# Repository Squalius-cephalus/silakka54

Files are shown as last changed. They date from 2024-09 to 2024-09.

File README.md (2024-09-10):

# Silakka54

Silakka54 is a RP2040 Zero based 54-key column staggered split keyboard. PCB uses hotswap sockets. Design is inpired from REVIUNG41 and Corne keyboards.

PCB is designed for MX style key switches. Current top plate only supports MX style switches. 5-pin switches is supported. I recommend using Vial firmware.

[QMK](https://github.com/qmk/qmk_firmwarehttp:// "QMK") and [Vial](https://github.com/vial-kb/vial-qmk "Vial") firmwares has very barebones key mapping. Good for quick testing.

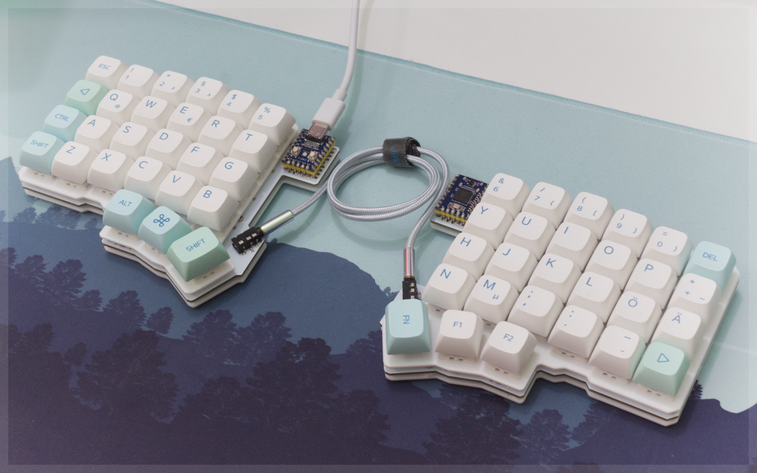
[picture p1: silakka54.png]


You can find build guide [here.](https://github.com/Squalius-cephalus/silakka54/blob/main/buildguide/README.md "here.")

PCB design uses footprints from [ScottoKeebs](https://github.com/joe-scotto/scottokeebs/tree/main/Extras/ScottoKicad "ScottoKeebs") and [kbd library.](https://github.com/foostan/kbd "kbd library.")

### TODO
1. Clean up code
2. Add RGB support
3. Make default QMK keymap usable

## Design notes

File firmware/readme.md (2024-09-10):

# silakka54

silakka54

*A short description of the keyboard/project*

* Keyboard Maintainer: [Squalius-cephalus](https://github.com/Squalius-cephalus)
* Hardware Supported: *The PCBs, controllers supported*
* Hardware Availability: *Links to where you can find this hardware*

Make example for this keyboard (after setting up your build environment):

    make silakka54:default

Flashing example for this keyboard:

    make silakka54:default:flash

See the [build environment setup](https://docs.qmk.fm/#/getting_started_build_tools) and the [make instructions](https://docs.qmk.fm/#/getting_started_make_guide) for more information. Brand new to QMK? Start with our [Complete Newbs Guide](https://docs.qmk.fm/#/newbs).

## Bootloader

Enter the bootloader in 3 ways:

* **Bootmagic reset**: Hold down the key at (0,0) in the matrix (usually the top left key or Escape) and plug in the keyboard
* **Physical reset button**: Briefly press the button on the back of the PCB - some may have pads you must short instead
* **Keycode in layout**: Press the key mapped to `QK_BOOT` if it is available

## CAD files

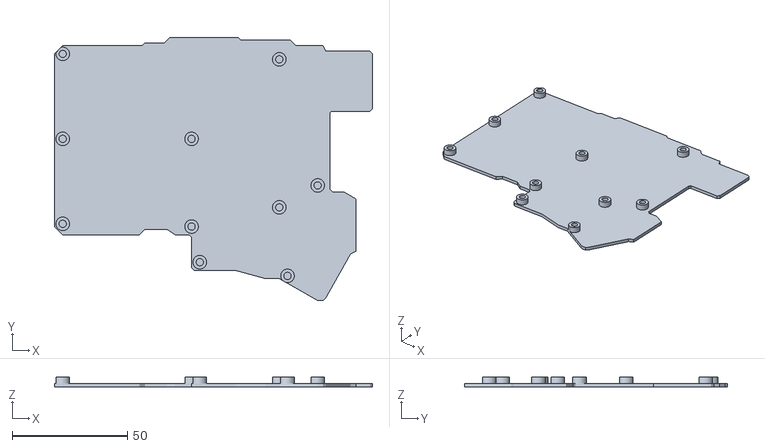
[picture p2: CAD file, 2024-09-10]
stl/bottom_plate.stl
138.1 x 114.3 x 4.48

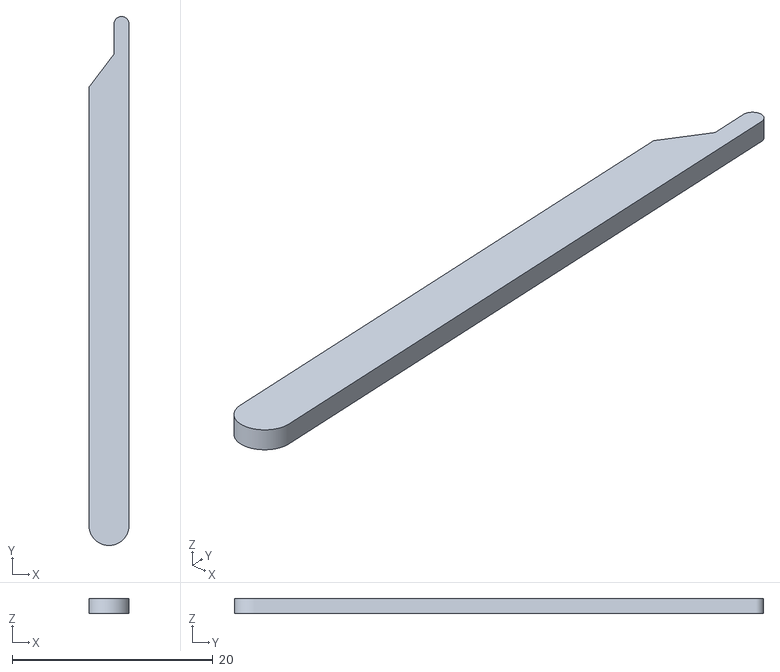
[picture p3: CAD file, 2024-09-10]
stl/tool.stl
4.00 x 52.8 x 1.50

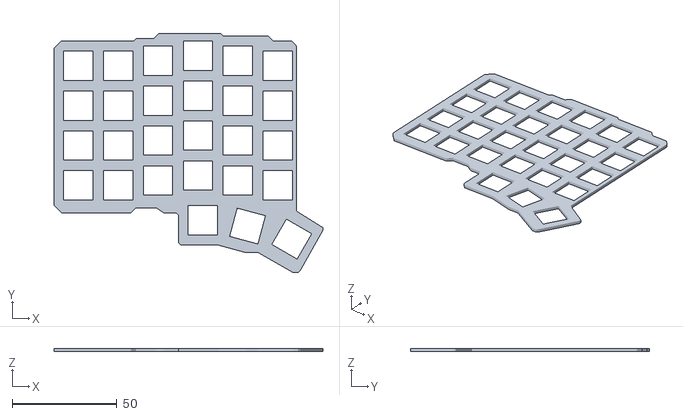
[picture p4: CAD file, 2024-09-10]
stl/plate.stl
128.6 x 114.3 x 1.60

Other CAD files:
stl/silakka54_stl.blend

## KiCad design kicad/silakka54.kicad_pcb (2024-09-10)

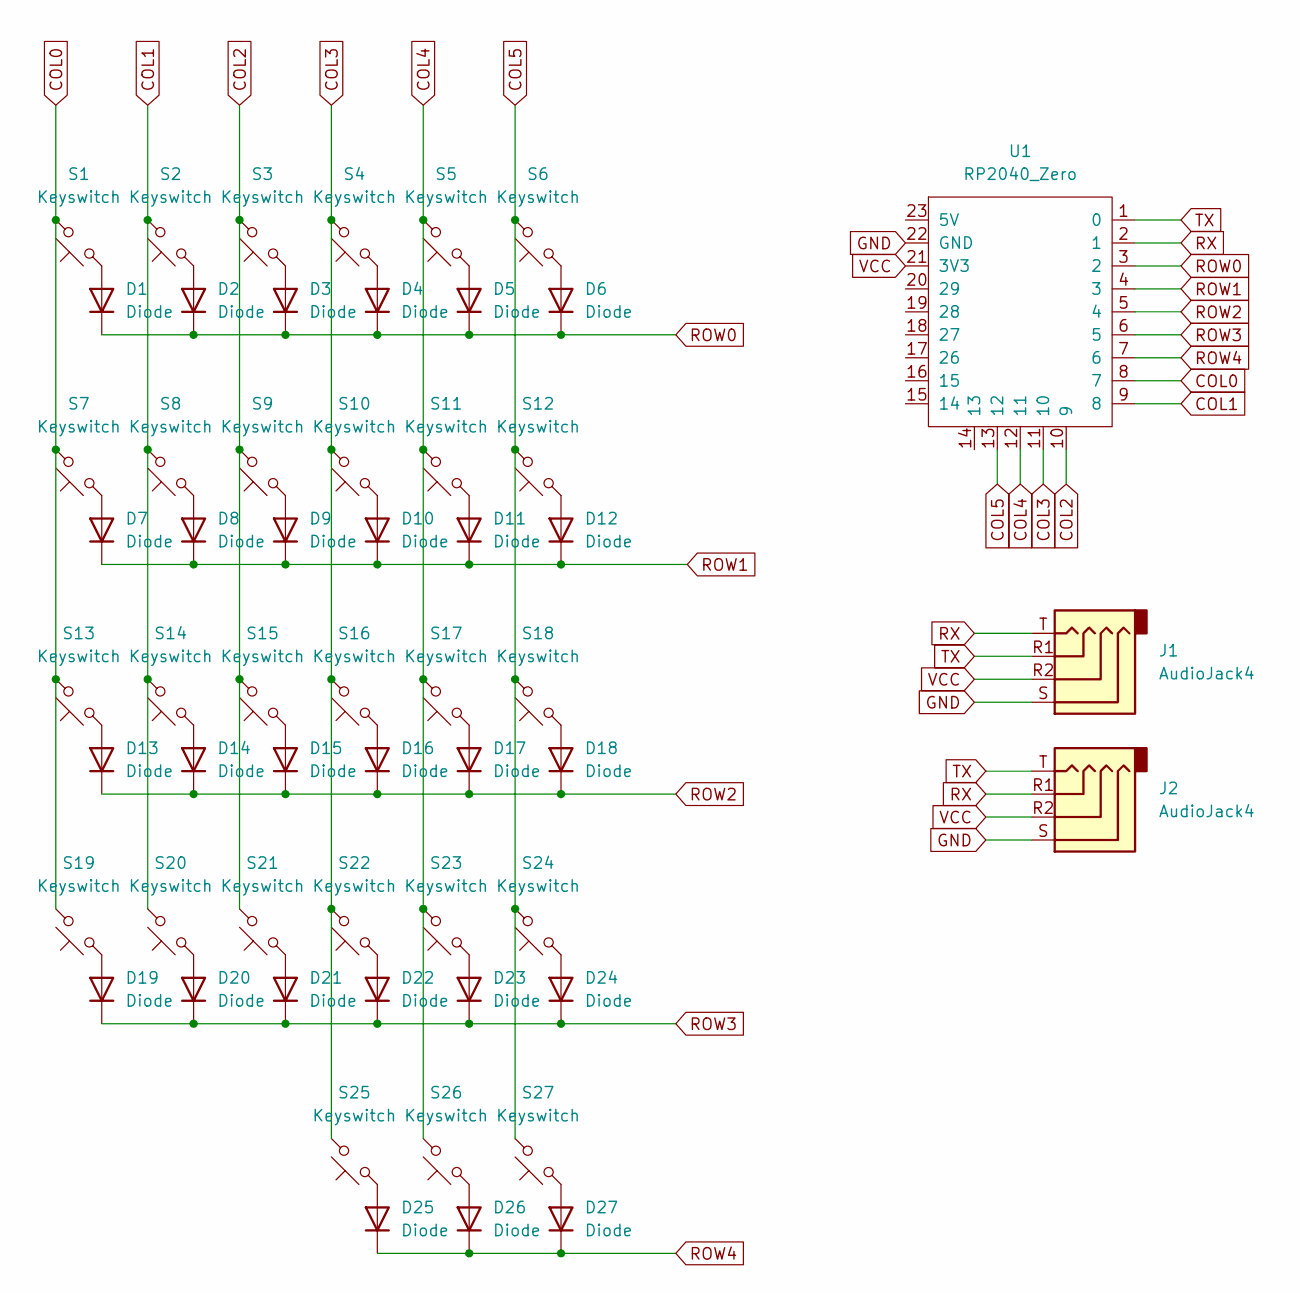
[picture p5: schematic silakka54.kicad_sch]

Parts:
D1, D2, D3, D4, D5, D6, D7, D8, D9, D10, D11, D12, D13, D14, D15, D16, D17, D18, D19, D20, D21, D22, D23, D24, D25, D26, D27: Diode; Diode_DO-35
J1, J2: AudioJack4; Jack_3.5mm_PJ320D_Horizontal
S1, S2, S3, S4, S5, S6, S7, S8, S9, S10, S11, S12, S13, S14, S15, S16, S17, S18, S19, S20, S21, S22, S23, S24, S25, S26, S27: Keyswitch; CherryMX_MidHeight_Hotswap
U1: RP2040_Zero

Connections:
COL0: S1.2, S7.2, S13.2, S19.2, U1.8 (7)
COL1: S2.2, S8.2, S14.2, S20.2, U1.9 (8)
COL2: S3.2, S9.2, S15.2, S21.2, U1.10 (9)
COL3: S4.2, S10.2, S16.2, S22.2, S25.2, U1.11 (10)
COL4: S5.2, S11.2, S17.2, S23.2, S26.2, U1.12 (11)
COL5: S6.2, S12.2, S18.2, S24.2, S27.2, U1.13 (12)
GND: J1.S, J2.S, U1.22 (GND)
unnamed: D1.2 (A), S1.1
unnamed: D2.2 (A), S2.1
unnamed: D3.2 (A), S3.1
unnamed: D4.2 (A), S4.1
unnamed: D5.2 (A), S5.1
unnamed: D6.2 (A), S6.1
unnamed: D7.2 (A), S7.1
unnamed: D8.2 (A), S8.1
unnamed: D9.2 (A), S9.1
unnamed: D10.2 (A), S10.1
unnamed: D11.2 (A), S11.1
unnamed: D12.2 (A), S12.1
unnamed: D13.2 (A), S13.1
unnamed: D14.2 (A), S14.1
unnamed: D15.2 (A), S15.1
unnamed: D16.2 (A), S16.1
unnamed: D17.2 (A), S17.1
unnamed: D18.2 (A), S18.1
unnamed: D19.2 (A), S19.1
unnamed: D20.2 (A), S20.1
unnamed: D21.2 (A), S21.1
unnamed: D22.2 (A), S22.1
unnamed: D23.2 (A), S23.1
unnamed: D24.2 (A), S24.1
unnamed: D25.2 (A), S25.1
unnamed: D26.2 (A), S26.1
unnamed: D27.2 (A), S27.1
ROW0: D1.1 (K), D2.1 (K), D3.1 (K), D4.1 (K), D5.1 (K), D6.1 (K), U1.3 (2)
ROW1: D7.1 (K), D8.1 (K), D9.1 (K), D10.1 (K), D11.1 (K), D12.1 (K), U1.4 (3)
ROW2: D13.1 (K), D14.1 (K), D15.1 (K), D16.1 (K), D17.1 (K), D18.1 (K), U1.5 (4)
ROW3: D19.1 (K), D20.1 (K), D21.1 (K), D22.1 (K), D23.1 (K), D24.1 (K), U1.6 (5)
ROW4: D25.1 (K), D26.1 (K), D27.1 (K), U1.7 (6)
RX: J1.T, J2.R1, U1.2 (1)
TX: J1.R1, J2.T, U1.1 (0)
VCC: J1.R2, J2.R2, U1.21 (3V3)

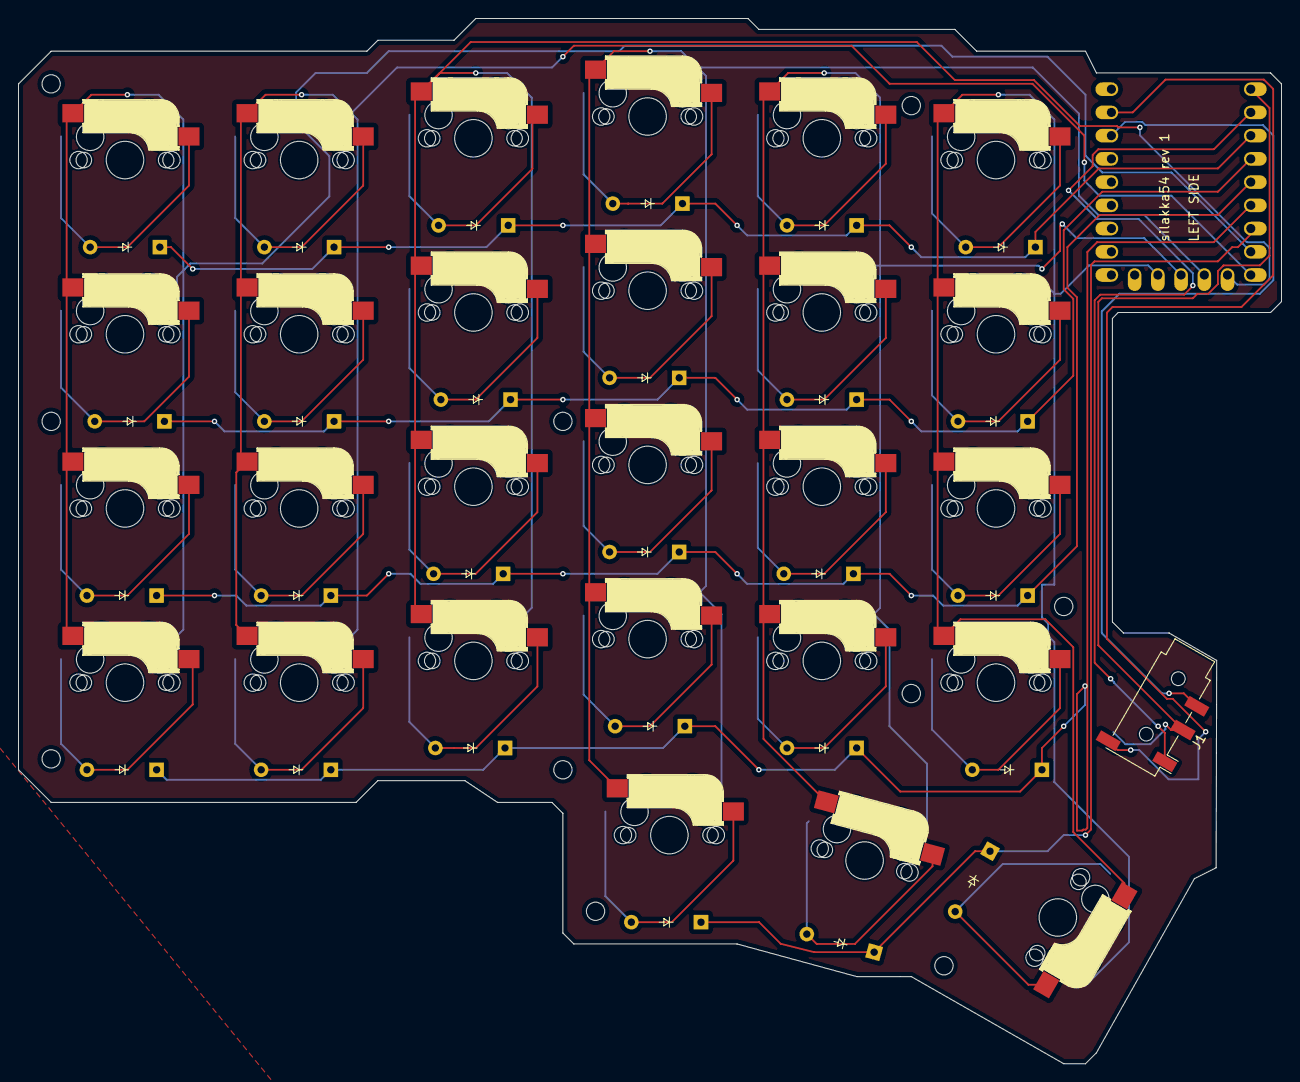
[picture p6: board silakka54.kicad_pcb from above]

Board: 2 copper layers, 138.1 x 114.3 mm, 57 parts (1 on the bottom side), 42 nets.

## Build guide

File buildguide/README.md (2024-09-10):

# Silakka54 - Build Guide

### Bill of materials
- **54x** MX compatible key switches
- **54x** Kailh Hotswap Sockets
- **54x** 1N4148 Diodes
- **52x** 1u keycaps
- **2x** 1.5u keycap
- **2x** RP2040 Zero
- **2x** PJ320D audio sockets
- **1x** TRRS audio cable
- **20x** M2 Heat set inserts, length 2mm(OD3.2mm)
- **20x** M2 bolts, length 4mm
- **2x** PCB
- **2x** Bottom plate
- **2x** Top plate

STL files do not require support, PLA plastic works well and printing of parts has been tested with a 0.4mm nozzle. Insert the heat set inserts into the bottom plates using a soldering iron.

The PCB is designed so that it can be used on both sides. Use the images as a reference.
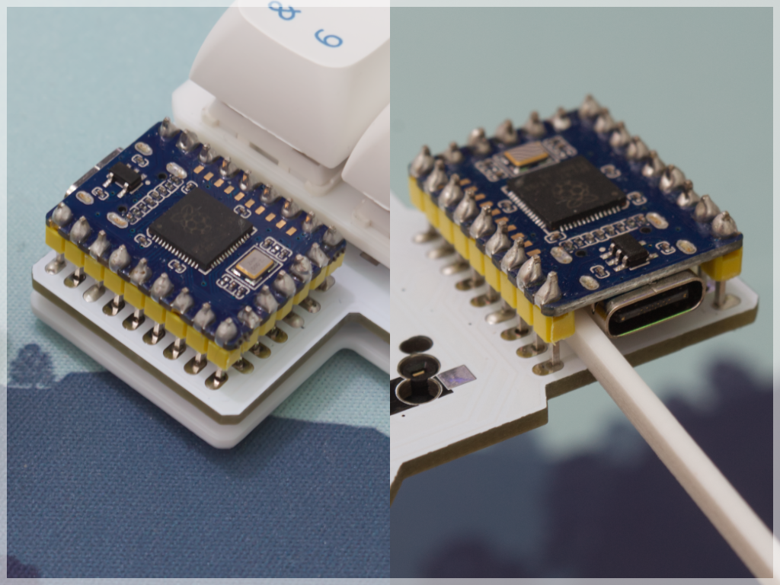
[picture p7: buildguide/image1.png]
Use a non-conductive tool to press buttons

The right side RP2040 needs to be flipped. Don't solder it too close to the PCB, leave a two-millimeter gap, the legs of the pin header should be long enough. There is no RESET pin on the Zero, so you need to have access to RESET and BOOT buttons if you want to change/upload the firmware.

**It is recommended that the firmware is already installed on the RP2040 Zero, the uf2 file can be found in the firmware folder. Double pressing the RESET button should put the Pico into bootloader mode if the firmware is installed.**

Solder the hotswap sockets, TRRS sockets, and RP2040's. Connect the two halves with the TRRS cable. Never connect or disconnect TRRS cable when keyboard is powered. This can lead to a short circuit.
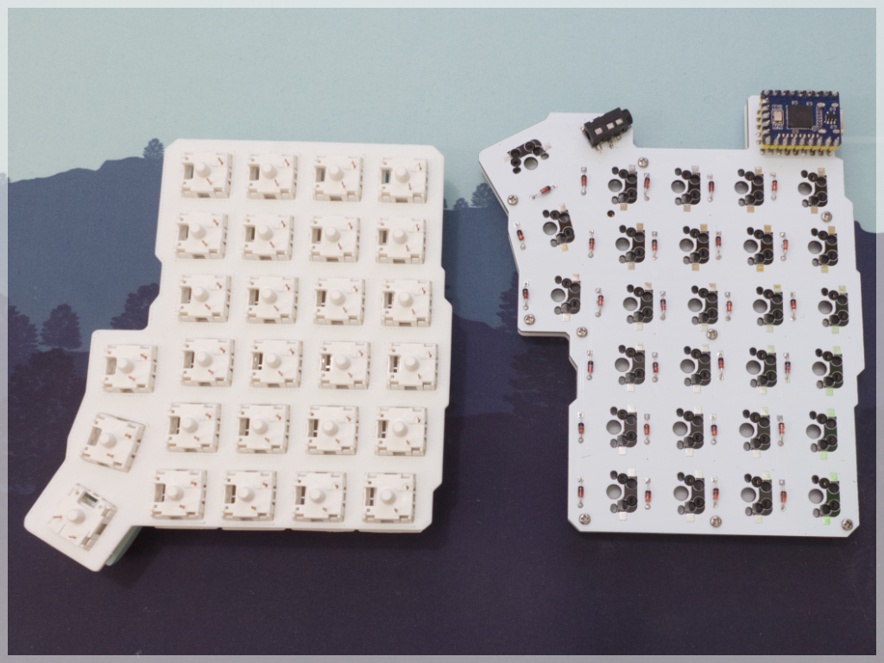
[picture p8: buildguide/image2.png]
Check the pins!

Next, attach the PCB to the plate with bolts. Then you can attach the switches to the top plate. Once all the switches are in place, make sure that the switch pins are not twisted or damaged. Press the top plate with the switches to the PCB.
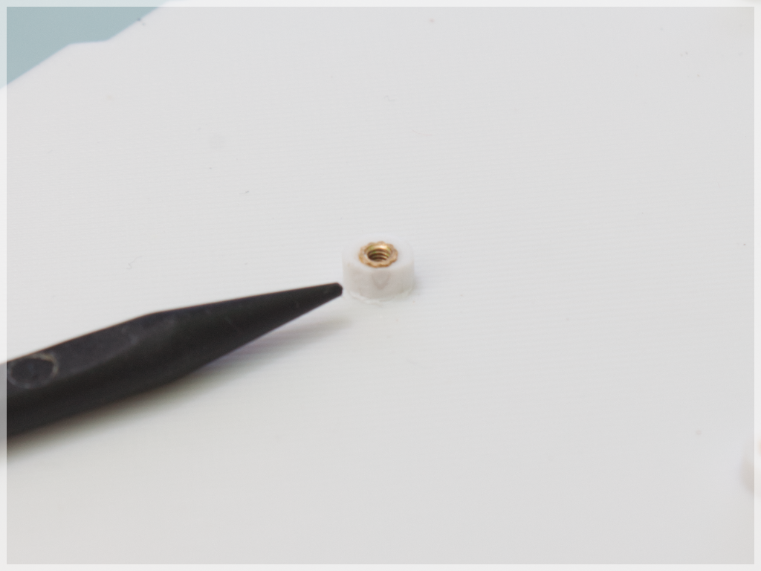
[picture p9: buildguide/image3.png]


If the PCB does not fit well with the base, cut small pieces off next to the threads. This problem will be fixed in a later version of the model.

I recommend putting small rubber feet on the bottom plate. If you installed the silakka54_vial firmware, you can use the Vial software to test the functionality of the switches in the matrix tester.

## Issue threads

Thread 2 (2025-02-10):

the current FW supports only 4 layers

seefood, 2025-02-10:
I'm sure 8 layers won't take up too much of the RP2040's storage :)

I haven't dived into the source of QMK-vial, so I am not sure how to add those in with a PR. sorry!

Squalius-cephalus, 2025-03-10:
Thanks for the suggestion, latest firmware now supports 8 layers [https://github.com/Squalius-cephalus/silakka54/releases/tag/v1.2](https://github.com/Squalius-cephalus/silakka54/releases/tag/v1.2)

ekchom, 2025-03-28:
Sorry for naive question, what is default key to change the layers ? I got board from aliexpress and just cant change the layer !

seefood, 2025-03-28:
don't remember anymore, why not just run vial and see?

ekchom, 2025-03-31:
I ran vial but not able to figure that out

seefood, 2025-03-31:
well, I am at work RN, I'll reset my keeb when I get home in a few hours and tell you what I find.

cadelossantos, 2025-04-10:
sorry for the noob question, but how do I know if I'm running the latest firmware? I re-flashed mine with the latest firmware but VIAL only reads 4 layers.

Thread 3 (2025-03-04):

Have to replug/reset keyboard everytime pc boots.

joshn77, 2025-03-04:
After pc is powered off then powered on again, keyboard doesn't work until it is either replugged or the reset button is pressed.

heliohsilva, 2025-03-10:
> After pc is powered off then powered on again, keyboard doesn't work until it is either replugged or the reset button is pressed.

This happens to me too. If you find anyway to fix it, please, share with me

Squalius-cephalus, 2025-03-10:
I made a new firmwares for testing https://github.com/Squalius-cephalus/silakka54/releases/tag/beta

Please report if this firmware version fixes the issue.

jomue, 2025-03-10:
Thanks, the new firmware seems to solve the issue for me.

Closed 2025-03-10.

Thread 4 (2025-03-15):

Vial key order is not left to right unlike other keyboards

HubKing, 2025-03-15:
I bought it from AliExpress, and with the firmware it came, this happened. When I tested Vial with a different keyboard model, the keys were filled from left to right, as I had expected.

I just updated the firmware with the version you released (8 layers), and the problem is the same. Is this because a wrong firmware setting, or is this because the Chinese manufacturer soldered something incorrectly?

https://github.com/user-attachments/assets/48db2cd4-dd0b-415f-a81c-489b6d97e8cb

anwerd, 2025-03-15:
Looks like this is an issue with the Vial GUI rather than the firmware itself.
https://github.com/vial-kb/vial-gui/issues/123

HubKing, 2025-03-15:
Thanks for your research. It seems that something was merged in August 2024 on that thread. Does it mean that it is already fixed, just not available yet?

TweetyDaBird, 2025-04-09:
This is a combination of both those issues really. The Vial GUI has no inherent knowledge of the positions of the keys, sop it follows the order in the keymap and vial.json. The 'fix' was implemented to actually follow the .json order correctly, but if that is badly ordered, you get your result. I'd start by making that ordered, re-compile and test. If the error then persist, it _may_ be a GUI error still.

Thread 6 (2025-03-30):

Case CAD files

FaFre, 2025-03-30:
Thank you a lot for this incredible keyboard! It's my first split and I'm really loving it!

As I travel a lot, I plan to carry the keyboard in my backpack. For protective reasons I want to create a case that completely encloses the keyboard. I was thinking of modifying the existing case by extruding the frame a bit more so it gets higher and  with having another bottom plate that goes on top (thinking of insetting some neodym magnets instead of screws there for quick attach/detach) I would have a robust solution that protects the keyboard well.

I just recently started using FreeCAD and nowhere advanced yet. For what I've seen now there are only the STL files of the case released which need to get reconstructed before modifying them. If you would be willing to release the CAD files (or have any suggestions how I can work with the existing STL files) that would help me a lot!

Thanks again for this great work!

heolfief, 2025-04-12:
Highly interested in the CAD files as well, plus this would make it truly open source hardware-wise.

Squalius-cephalus, 2025-04-15:
I added the case files and STEP versions of them. I recommend the STEP files for editing, I may at some point redo the case in FreeCAD.

Closed 2025-04-15.

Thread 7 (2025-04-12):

How can i recompile to .uf2 file?

rafaeloledo, 2025-04-12:
I want to define some constants like `#define MK_3_SPEED`.

I'm a programmer, so you can give me instructions.

rafaeloledo, 2025-04-12:
Edit:

I've executed these steps:

```sh
git clone https://github.com/vial-kb/vial-qmk
```

Install deps:

```
gcc-arm-embedded
qmk
```

an then execute the below command inside the cloned repo root dir.

```sh
qmk setup
make git-submodules
make silakka54:vial
```

The file `silakka54_vial.uf2` is the result in the root.

The compiled file is the same for both sides? 🤔

rafaeloledo, 2025-04-12:
Edit:

I've managed to flash it following the instructions.

- Press two time the reset
- Mount the file system
  - `lsblk -fa`
  - `sudo mount /dev/sdX1 ~/silakka54
  - `sudo cp silakka54_vial.uf2 ~/silakka54`

It automatically flashes-on-copy. After 30s it is now valid.

The only problem i'm having now is that the LEFT layout is the default and when i flash it on the right side, it is interpreted as LEFT.

So must be some flag to specify the sides? 🤔

rafaeloledo, 2025-04-12:
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

This is my overlay for a better mouse-kbd experience. Waiting for more instructions on how to compile for a specific side.

Squalius-cephalus, 2025-04-14:
If you want to make firmware for the right side, add `#define MASTER_RIGHT` to the `keyboards/silakka54/config.h`. Compile the firmware, comment the line and now you can compile firmware for the left side.

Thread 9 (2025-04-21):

One question...

meencantaesto, 2025-04-21:
Hi, @Squalius-cephalus,  first of all, what an amazing work, congratulations !!!

I'm about to build my own Silakka54 and I'm wondering if a BLE version is possible using Nice!Nano v2 and ZMK... and as the master of DIY keyboards I want to ask you for your opinion.. what do you think? Of course it implies to put a battery, charging circuit, update firmware... is it feasible?

Thank you very much for your design !!!

humanplayer2, 2025-08-07:
If this is still relevant, then I think:
- Not plug-and-play.
- It's doable if you solder it up right.

[The website](https://squalius-cephalus.github.io/silakka54/index.html) that "Silakka54 has some unused pins, GP12, GP13, GP15, GP26, GP27, GP28 and GP29 are not used."

This indicates GP9, GP10 and GP11 are use. These are on the bottom row of the Zero ([cf. this](https://www.waveshare.com/wiki/RP2040-Zero)).

The larger nice!nano does not have pins in those positions, so you cannot just drop it in (it's also longer of course, but has almost the same width, so maybe the side-pinholes could be made to align even if the whole thing would extend beyond the pcb edges).

That said, I'm sure you can wire the nice!nano to the Silakka54 pcb and make that work. Maybe you can use some side-pins directly, but you'll need to handwire some, too. Maybe some side-pins can be used to fixate it to the pcb. Once you have the pcb and mcu hooked up, I don't see why battery, wireless and ZMK would pose a problem (baring that I have no ZMK, wireless or RGB experience).

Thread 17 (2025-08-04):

Half of keyboard unresponsive after certain amount of time

connornguyxn, 2025-08-04:
USB was connected to the left MCU. After being left untouched for some time (probably 10 mintues or more after some testing), the right half of the keyboard became unresponsive. Both halves function normally after replugging USB.

I have no experience with Vial or QMK, but this might be a firmware configuration issue. The problem only exists with firmware version 1.2 and above.

connornguyxn, 2025-08-08:
@dagrlx Thank you

> Restore the keyboard firmware to version 1.2 for now

@Squalius-cephalus I've had the problem since 1.2 (my original comment metioned it), so maybe this could narrow the search down a litte.

dagrlx, 2025-08-19:
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

A new beta version 1.3 was released 3 days ago, try it and see how it goes. I just installed it and will be testing it.
I have been doing well with my own build but to support the project I will be testing this new version.

connornguyxn, 2025-08-20:
> https://github.com/Squalius-cephalus/silakka54/releases/tag/v1.3
>
> There is now two versions, try the NO_USBDETECT version if keyboard becomes unresponsive. I have theory that `#define SPLIT_USB_DETECT` causes some problems.

The issue still persists with this new version for me.

connornguyxn, 2025-08-25:
> I guess you already tried to rule out problems with the trrs cable, USB port, hub if you use one.

Swapping TTRS cables was the first thing I did. I do use a hub with the keyboard, so I'm gonna try another cable and plug it in directly.

> Have you tried compiling the firmware yourself?

Not yet, but noted.

Thanks for the pointers.

connornguyxn, 2025-09-19:
> Over the past week, I noticed that one side of my keyboard suddenly stopped working sometimes. The culprit turned out to be a faulty TRRS connector on the circuit board.

Good to know.

I was also suspecting some kind of hardware error since it was always the right half malfunctioning no matter what side I plug it in. Windows also shows an USB error when this happens if it's plugged into the right half.

I'm planning to replace the TTRS port first, then the MCU if things don't improve. Gonna take a lot of prep though since I haven't soldered before, but yeah.

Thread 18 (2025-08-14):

Homerow Mods + Chordal Hold + Permissive Hold Behavior

addisonjones3, 2025-08-14:
Hi all, typing this from my silakka54 now so first off thanks for all your hard work!

I'm attempting to use the combination of homerow mods and Permissive Hold + Chordal Hold that was made available in the Vial `0.7.4` firmware and `1.2` release in this repo. I'm finding some inconsistent behavior I'm wondering might be related to #4 .

My settings are:
- Tapping Term: 200
- Permissive Hold
- Chordal Hold
- Ctrl, Alt, GUI, Shift as homerow mod order (on the left)

The inconsistent behavior is that when typing the following sequence:
1. f <down>
2. p <down>
3. p <up>
4. f <up>
I would expect this to produce a `P`, but most of the time produces a `fp` sequence. This isn't the case with `fo` which almost always consistently produces the desired `O`.

For instance with the same rhythm to the chording, I produce:
YUIOfp
going across the right hand top letter row.

This happens on other keys and mods using `MT` and is most problematic with GUI on Mac.

I was wondering if this could be do to the [Chordal Hold Handedness](https://docs.qmk.fm/tap_hold#chordal-hold-handedness) outlined in that section and that perhaps the inference of the handedness is flawed in some way due to the keys being seen as on the incorrect side/hand.

For example, `jp` chorded reliably produces `P`.

Thanks and let me know if any more information would be helpful.

addisonjones3, 2025-08-14:
I think I might have narrowed it down to the keymap section of the `vial.json` file. When looking at the order of the keys added, it appears when adding values to keys they follow the order in which they were added to the keymap. I might try to retool it to add the keys in sequence even if it becomes tiresome to keep changing the x and y coords. I believe this could be relevant to #4 as well.

addisonjones3, 2025-08-31:
I was having a tough time with misfiring mods with chordal hold so I tried out a dedicated thumb shift key for a bit, but I ended up going back to homerow + chordal hold and it seems to be working really well now. And I've gotten a lot more practice so it's coming more naturally now.

Here are my settings now:
Tapping Term: 280
Permissive Hold: On
Hold on Other Key Press: Off
Quick-Tap-Term: 70
Chordal Hold: On
Flow Tap: 60

I did what I could to follow [urob's timeless homerow mods](https://github.com/urob/zmk-config?tab=readme-ov-file#timeless-homerow-mods) and I'm getting 0 misfires. If anything the thing I'm struggling with is is to get shift to trigger when I want it to and not delaying enough. (that would be solved by lowering the flow tap value, but that's causing more accidental triggers so 60 is the sweet spot for me right now.

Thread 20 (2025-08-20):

Feature Request: additional Kailh Choc option

kolbenhans, 2025-08-20:
Hey, saw the "lily58 pro" supporting MX and also Kailh Choc switch sockets on the pcb.

I would love to have this option for the silakka54. A low profile Silakka54 would be nice, right?

regards

krank56, 2025-08-24:
up
